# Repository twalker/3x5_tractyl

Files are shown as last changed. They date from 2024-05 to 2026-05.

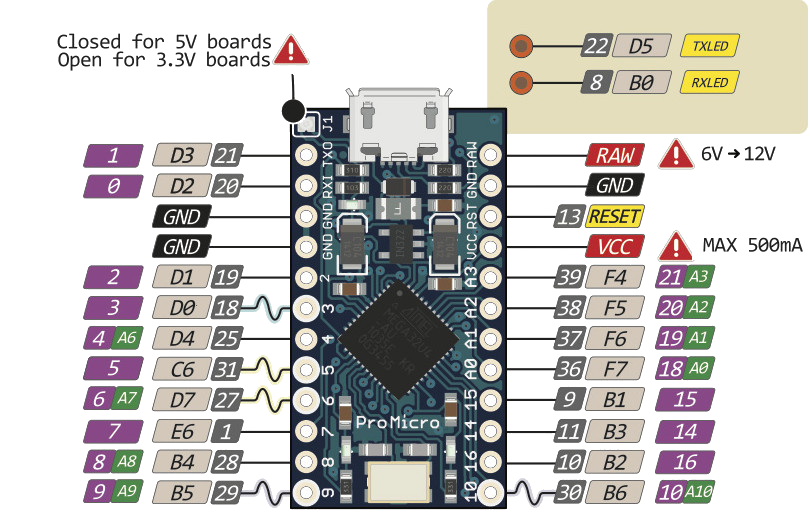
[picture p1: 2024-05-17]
wiring-diagram/pro_micro_pinout2.png

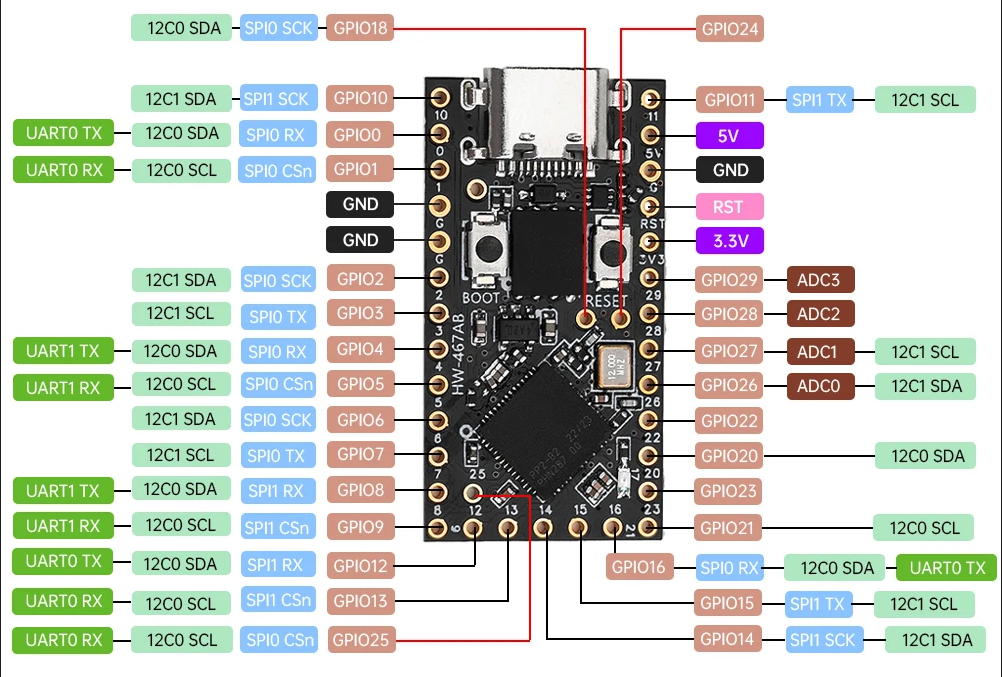
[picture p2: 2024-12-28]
v2/rp2040-promicro-pinout.png

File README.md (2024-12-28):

# 3x5_tractyl

A 3x5 Dactyl keyboard with a trackball on the top left.

# Parts list

- [PMW3389 Motion Sensor](https://www.tindie.com/products/citizenjoe/pmw3389-motion-sensor)
- [Elite-C](https://keeb.io/products/elite-c-low-profile-version-usb-c-pro-micro-replacement-atmega32u4)
- [Cosmos keyboard configurator](https://ryanis.cool/cosmos/beta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)
  v3: https://ryanis.cool/cosmos/beta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
  v4: https://ryanis.cool/cosmos/beta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
  https://ryanis.cool/cosmos/beta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
  Low pro, adjusted stagger, and key spacing:
  https://ryanis.cool/cosmos/beta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
  Lowpro v2:
  https://ryanis.cool/cosmos/beta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
  v2 no web:

https://ryanis.cool/cosmos/beta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

Updated palm wrests:
https://ryanis.cool/cosmos/beta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

Beta v3 WIP:
https://ryanis.cool/cosmos2/beta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

# Dactyl build guides

- https://klotzandrew.com/blog/building-a-dactyl-keyboard-from-scratch
- https://www.reddit.com/r/olkb/comments/c8hjn1/help_me_correctly_programming_my_new_born_dactyl/
- https://github.com/aleung/mini-thumb-dactyl-keyboard
- https://github.com/dereknheiley/compactyl/tree/master
- https://github.com/ArtiomSu/qmk_firmware/tree/artiom_dactyl/keyboards/artiomsu_dactyl
- https://medium.com/swlh/complete-idiot-guide-for-building-a-dactyl-manuform-keyboard-53454845b065
- https://github.com/noahprince22/tractyl-manuform-keyboard

## Issues

- Could not configure dactyl generator with trackball holder. No response to github issue.
- No model for a 38mm trackball. Needed to model a trackball holder in Fusion 360.
- Diode in the wrong direction.
- 3-4 Switch wires disconnected.
- Trackball sensor too far from trackball to register movement.
- Case model had corrupted geometry on thumb cluster bottom.
- Case printing had layer shifts.
- MCU holder was too tight.
- Trackball wiring misconfigured (B2 and B3 in wrong order).
- Dupont connectors pushing and popping keys out--needed to replace microcontroller with 90deg headers.
- Keys popping out -- needed to glue switches down.

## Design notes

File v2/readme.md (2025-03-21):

# V2 - mx

- Ameoba kings with MX switches
- Beta v3

### With trackball

https://ryanis.cool/cosmos/beta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

### Adjusted to MX switches (std key spacing)

https://ryanis.cool/cosmos/beta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

## Adjusted MCU

https://ryanis.cool/cosmos/beta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

## 1.5 u thumbs

https://ryanis.cool/cosmos/beta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

#### Adjusted MCU 2

https://ryanis.cool/cosmos/beta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

### Skree pcb, sensor, and des keycaps

- 15 -> 20 deg column curvature

https://ryanis.cool/cosmos/beta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

Adjusted trackball position
https://ryanis.cool/cosmos/beta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

With left shaper key
https://ryanis.cool/cosmos/beta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

with adjusted MCU
https://ryanis.cool/cosmos/beta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

with larger keys on thumbs (1, 1.25, 1.5)
https://ryanis.cool/cosmos/beta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

With mcu at top (Printed) ( cosmoskreedes_v1):
https://ryanis.cool/cosmos/beta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

Trying another print :
https://ryanis.cool/cosmos/beta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

## Printed left side

Possible issues:

Resolved:

- key spacing is tight with MT3. bearable
- microcontroller mount does not quite fit (blocking screw) -- made 2nd attempt--11.5, 90deg
- Do the single key w/choc sockets fit the ameoba king holders?
- I really want choc spacing --quieter and lighter. Not in this version. Want to reuse wire harness.
- mount PWM3360 seems to have has inadequate clearence (rotated for better access)
- 3mm Ceramic balls seem too small (Need to use glue)

Unresolved:

---

### WIP Choc version:

https://ryanis.cool/cosmos/beta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

with screen and rounded.
https://ryanis.cool/cosmos/beta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

To do:
Try keyspacing: 19.5 x 18.5
Kailh Choc keys are 18mm wide and 17mm tall.
https://ryanis.cool/cosmos/beta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

With mouse thumb key:
https://ryanis.cool/cosmos/beta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

- Adjusted stagger and lowered trackball

```
  pinky: -13
  ring: 0
  middle: 2.8 => 4.5
  index: 0 => -1.5
  inner: 0 => -3.5
```

https://ryanis.cool/cosmos/beta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

Adjusted screen position and rounded sides:
https://ryanis.cool/cosmos/beta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

With right side separated and cleaned up
https://ryanis.cool/cosmos/beta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

Printed prototype 2 ...
Love it.

Tweaks to do:

- Tenting: 15 -> 20 deg?, no. when hangingo the edge there's some tension with 20deg, but otherwise yes.
  x Split the difference: 15 -> 17.5
- Stagger: Good. No changes.
- Ball placement
  x X? + 2-3mm to the right?
  - Y?
  - Z?
- Screen: -Y
  - moved screen to side, so it'd be easy to make a screenless verison. Used 1.5u shaper instead.
- Ring anchor:

  - level instead of sloped-- so the finger doesn't slide off
  - +y 1-3mm
  - maybe rotate 45deg so pinky can rest too

- Thumb anchor key:
  - Maybe -0.5mm - 1mm Z, no.
  - moving ~2mm Y
    Adjustments 1: tenting, move screen, ball placement
    https://ryanis.cool/cosmos/beta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

Adjusted top right anchor:
https://ryanis.cool/cosmos/beta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
With reset holes:
https://ryanis.cool/cosmos/beta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

Repositioned reset holes:
https://ryanis.cool/cosmos/beta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

Repositioned index anchor:
https://ryanis.cool/cosmos/beta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

Power buttion instead of rocker switch:
https://ryanis.cool/cosmos/beta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

Another print

Switch to QMK
https://ryanis.cool/cosmos/beta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

1mm Closer thumbs
https://ryanis.cool/cosmos/beta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

No OLEDs WIP
https://ryanis.cool/cosmos/beta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

https://ryanis.cool/cosmos/beta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

mcu position okay
https://ryanis.cool/cosmos/beta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

No right spacer key
https://ryanis.cool/cosmos/beta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

Updated screws to 7
https://ryanis.cool/cosmos/beta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

trackball mount and 2u left landing spacer, lower left mouse key
https://ryanis.cool/cosmos/beta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

!!another print (fantasy forest green). And built!!

Attempt at wrist wrests:
https://ryanis.cool/cosmos/beta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

---

TODO:
x adjust stagger (especially index)

x lower trackball?
x Adjust angle/location of pinky anchor
x adjust MCU location
x Cleanup right side
x add reset hole

---

# Build

1. Flash MCU, connect sensor, and test trackball (DONE)
2. Glue ceramic balls to crater (DONE)
3. Update Wiring Diagram
4. Use test print to prototype wiring technique with diodes
5. Glue hotswap sockets
6. Wire rows and columns
   - Rows will be composed of diodes with legs (end near center, current outward)
   - Columns use small connector wires
7. Wire TRRS and Reset button
8. Wire Rows and columns
9. Refactor keymap for 38 keys (3x5_4)

### Custom firmware

layout json
https://github.com/qmk/qmk_firmware/blob/master/docs/reference_configurator_support.md
https://github.com/qmk/qmk_firmware/blob/master/docs/reference_info_json.md
https://www.youtube.com/watch?v=bMTp51j7-iY&t=550s

```json
/*
**legend**
layout: A list of key dictionaries comprising the layout. Each key dictionary contains
  x:      The key's X-axis location, in key units from the keyboard's left edge.
  y:      The key's Y-axis location, in key units from the keyboard's top (rear-facing) edge.
  matrix: The matrix position for the key. Example: [0, 4] (row 0, column 4)
*/
    "layouts": {
        "LAYOUT": {
            "layout": [
                // matrix: [RowPosition, ColPosition], "x": ColumnPositon, "y": RowPosition},
                {"matrix": [0, 0], "x": 0, "y": 0},
            ]
        }
    }
```

```json
        "LAYOUT_split_3x5_4": {
            "layout": [
                {"matrix": [0, 0], "x": 0, "y": 0},
                {"matrix": [0, 1], "x": 1, "y": 0},
                {"matrix": [0, 2], "x": 2, "y": 0},
                {"matrix": [0, 3], "x": 3, "y": 0},
                {"matrix": [0, 4], "x": 4, "y": 0},

                {"matrix": [4, 0], "x": 10, "y": 0},
                {"matrix": [4, 1], "x": 11, "y": 0},
                {"matrix": [4, 2], "x": 12, "y": 0},
                {"matrix": [4, 3], "x": 13, "y": 0},
                {"matrix": [4, 4], "x": 14, "y": 0},

                {"matrix": [1, 0], "x": 0, "y": 1},
                {"matrix": [1, 1], "x": 1, "y": 1},
                {"matrix": [1, 2], "x": 2, "y": 1},
                {"matrix": [1, 3], "x": 3, "y": 1},
                {"matrix": [1, 4], "x": 4, "y": 1},

                {"matrix": [5, 0], "x": 10, "y": 1},
                {"matrix": [5, 1], "x": 11, "y": 1},
                {"matrix": [5, 2], "x": 12, "y": 1},
                {"matrix": [5, 3], "x": 13, "y": 1},
                {"matrix": [5, 4], "x": 14, "y": 1},

                {"matrix": [2, 0], "x": 0, "y": 2},
                {"matrix": [2, 1], "x": 1, "y": 2},
                {"matrix": [2, 2], "x": 2, "y": 2},
                {"matrix": [2, 3], "x": 3, "y": 2},
                {"matrix": [2, 4], "x": 4, "y": 2},

                {"matrix": [6, 0], "x": 10, "y": 2},
                {"matrix": [6, 1], "x": 11, "y": 2},
                {"matrix": [6, 2], "x": 12, "y": 2},
                {"matrix": [6, 3], "x": 13, "y": 2},
                {"matrix": [6, 4], "x": 14, "y": 2},

                {"matrix": [3, 1], "x": 1, "y": 3},
                {"matrix": [3, 2], "x": 2, "y": 3},
                {"matrix": [3, 3], "x": 3, "y": 3},
                {"matrix": [3, 4], "x": 4, "y": 3},

                {"matrix": [7, 0], "x": 10, "y": 3},
                {"matrix": [7, 1], "x": 11, "y": 3},
                {"matrix": [7, 2], "x": 12, "y": 3},
                {"matrix": [7, 3], "x": 13, "y": 3}
            ]
        }
```

homerow mod implementation to try:
https://www.reddit.com/r/ErgoMechKeyboards/comments/1f18d8h/i_have_fixed_home_row_mods_in_qmk_for_everyone/

```
#undef QUICK_TAP_TERM
#undef TAPPING_TERM
#define TAPPING_TERM 250
#define QUICK_TAP_TERM 120
#define PERMISSIVE_HOLD
#define IGNORE_MOD_TAP_INTERRUPT
```

matrix explanation (see keymap setup: 1830 ):
https://www.youtube.com/watch?v=bMTp51j7-iY&t=551s

---

## Case adjustments needed

- [x] 1mm or more bottom clearance for mouse sensor PCB, or raise ball up--it was touching bottom plate.
- [x] Raise trackball could up (z) a few millimeters.
- [x] Remove the reset button hole
- [x] Upper corner of sensor PCB touched wall and needed to be rounded.
- [x] Use the Skree trackball mount instead of the QMK on (!! Skree trackball PCB footprint only works for wireless.)
- [ ] Reorder row pins for a clear left to right wiring
      From:

```
        "rows": [ "GP16", "GP15", "GP14", "GP13" ]
```

To:

```
        "rows": [ "GP12", "GP13", "GP14", "GP15" ]
```

https://ryanis.cool/cosmos/beta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

https://ryanis.cool/cosmos/beta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

Trackball Repositioned
https://ryanis.cool/cosmos/beta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

a bit more
https://ryanis.cool/cosmos/beta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

mcu's Repositioned
https://ryanis.cool/cosmos/beta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

lower tenting angle 17.5 -> 15, lower thumb clusters and add row curve
https://ryanis.cool/cosmos/beta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

Reposition trackball toward index finger
https://ryanis.cool/cosmos/beta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

Printed 2.4!!!
Mouse sensor mount is wrong one! Need the QMK mount, not the Skree mount.
TODO: Reuse left case for wireless version.

verison 2.41
https://ryanis.cool/cosmos/beta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

### Printed 2.4.1!!!!

Adjustments
Case Tweaks

### TODO:

- [ ] R2C5 hotswap bumps into thumb cluster, needs more room. highten super thumb or move away from matrix.
- [ ] trackball mount screws obscured by case screws

---

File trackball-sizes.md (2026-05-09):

## Trackball sizes

- 34mm Standard (too small)
- 38mm Ploopy Nano (just right)
- 45mm Ploopy Adept (tracking issues?)

## Cosmos keyboard supported sizes
- 25mm
- 34mm (std)
- nano size not availble
- 40mm (Kensington Orbit)
- 43mm (Logitech Trackman T-RB22)
- 44mm (Kensington and Elecom DEFT)
- 45mm (Ploopy classic, adept)
- 46mm (Microsoft Trackball Explorer)
- 50mm
- 52.5mm (Standard size of snooker balls)
- 57.15mm (Standard size of American billiard balls)

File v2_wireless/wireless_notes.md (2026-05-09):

## Wireless version

starting with version 2.41

- [x] Thumb supers heightened
- [x] oled screens added (do not persist in cosmos)
- [ ] battery space determined

https://ryanis.cool/cosmos/beta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

with switch holes
https://ryanis.cool/cosmos/beta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

3 screws and mcu's placed
https://ryanis.cool/cosmos/beta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

switches added 5x7
https://ryanis.cool/cosmos/beta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

cosmos_choc_hotswap_wireless_v2.5
https://ryanis.cool/cosmos/beta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
was somehow deleted !!!!

Printed:
- Galaxy Black

cosmos_choc_hotswap_wireless_v2.6 -- redone; Cosmos is forgetting oled screens!!!

https://ryanis.cool/cosmos/beta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
---
## clemenza plus
https://ryanis.cool/cosmos/beta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

https://ryanis.cool/cosmos/beta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

https://ryanis.cool/cosmos/beta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

only on oled:
https://ryanis.cool/cosmos/beta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

With 7.5mm  BTU
https://ryanis.cool/cosmos/beta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

closer thumb cluster
https://ryanis.cool/cosmos/beta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

balls for trackball
https://ryanis.cool/cosmos/beta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

with hillside pcbs
https://ryanis.cool/cosmos/beta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

Luca printed with 5 Column, hillside PCBs, and BUILt.

TODO for Luca v2:
Make 2 versions, a 45mm and a 34mm for work.

-[x] use 3DP sockets instead of pcb
-[x] Fewer base screws
-[x] Don't block sensor screw holes
-[x] Sit's too high at twenty degree angle. Can the overall case be lowered? Smaller ball, or move ball right. smaller ball
-[x] Adust Left power switch and MCU position if possible. 
-[x] Ball position may be a bit too far left, wait so see. No, it's great for 45mm
-[x] Try 7.5 BTU for trackball
-[x] Smaller ball

https://ryanis.cool/cosmos/beta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

34mm smaller ball
https://ryanis.cool/cosmos/beta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
 
 smaller power switch
 https://ryanis.cool/cosmos/beta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

fewer screws
https://ryanis.cool/cosmos/beta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

Move ball offset x from 0 to 11 like pentangeli 
https://ryanis.cool/cosmos/beta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

Lower thumb cluster offset Z from 7.1 to 9
https://ryanis.cool/cosmos/beta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

Back to 45mm ball
https://ryanis.cool/cosmos/beta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

Printing

TODO:
- Fix thumb key spacing
- Rewire columns to be more vertically aligned.
- Add dongle for better mouse responsiveness?

---
34mm ball, adusted thumb key spacing, hillside PCBs
name: luca_v2_hs_sm
https://ryanis.cool/cosmos/beta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

Printed
TODO:
- [x] Fix thumb key rotation to match pentangeli
- [ ] move ball right--further towad to index
- [ ] Rethink power switch
- [ ] consider reset button hole

Fixed thumb key

https://ryanis.cool/cosmos/beta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
---
Moved ball, 12 => 8 sides.

https://ryanis.cool/cosmos/beta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

Add reset switch hole:
https://ryanis.cool/cosmos/beta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
https://ryanis.cool/cosmos/beta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
Adjust reset hole to 4.5mm
https://ryanis.cool/cosmos/beta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

Printed with wrong 3dp sockets

fixed sockets
https://ryanis.cool/cosmos/beta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

Assembled (2/22/2026)

### hs sm TODO:
- [x] move trackball back left
- [x] remove reset switch hole
- [x] add extra screws
- [x] adjust power switch width
Use this case for next hillside pcb small trackball case:
https://ryanis.cool/cosmos/beta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

### Back to 45mm with rollers (supposedly quieter)
## hs lg WIP (with rollers)
https://ryanis.cool/cosmos/beta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
https://ryanis.cool/cosmos/beta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

bumpon bottom
https://ryanis.cool/cosmos/beta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

To print: luca v2 hs_lg:
https://ryanis.cool/cosmos/beta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

luca_v2_hs_lg.3mf

v2.1 (larger power switch holes)
https://ryanis.cool/cosmos/beta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

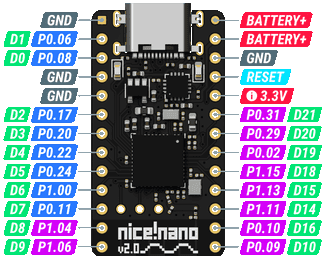
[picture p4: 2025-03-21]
wiring-diagram/nice_nano_pinout-v2_cropped.png

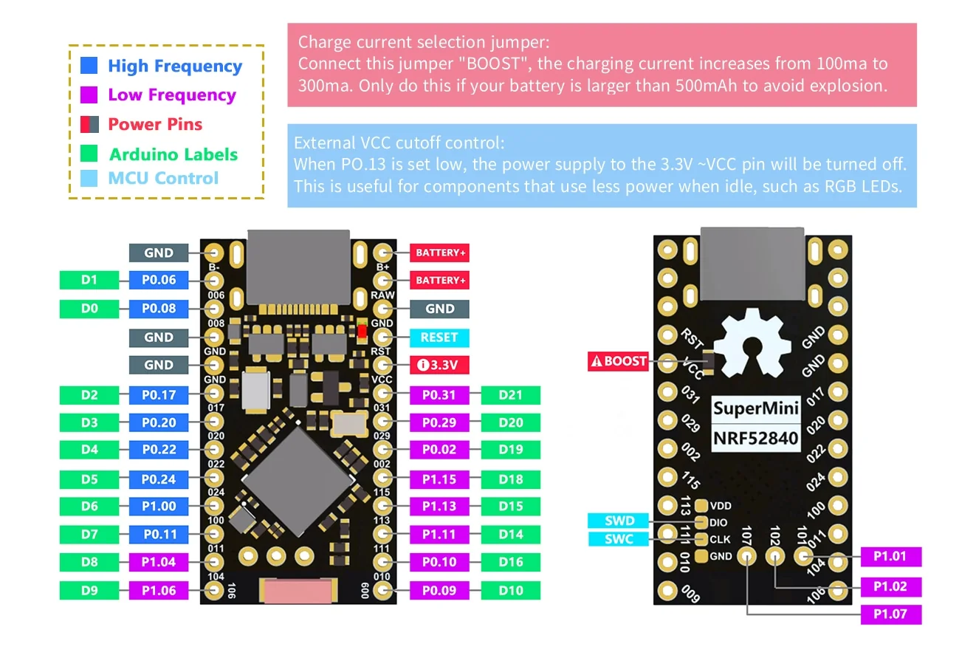
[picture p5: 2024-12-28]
wiring-diagram/supermini-nrf52840-a-6-nice-nano-2-0-compatible-mcu-pinout.webp

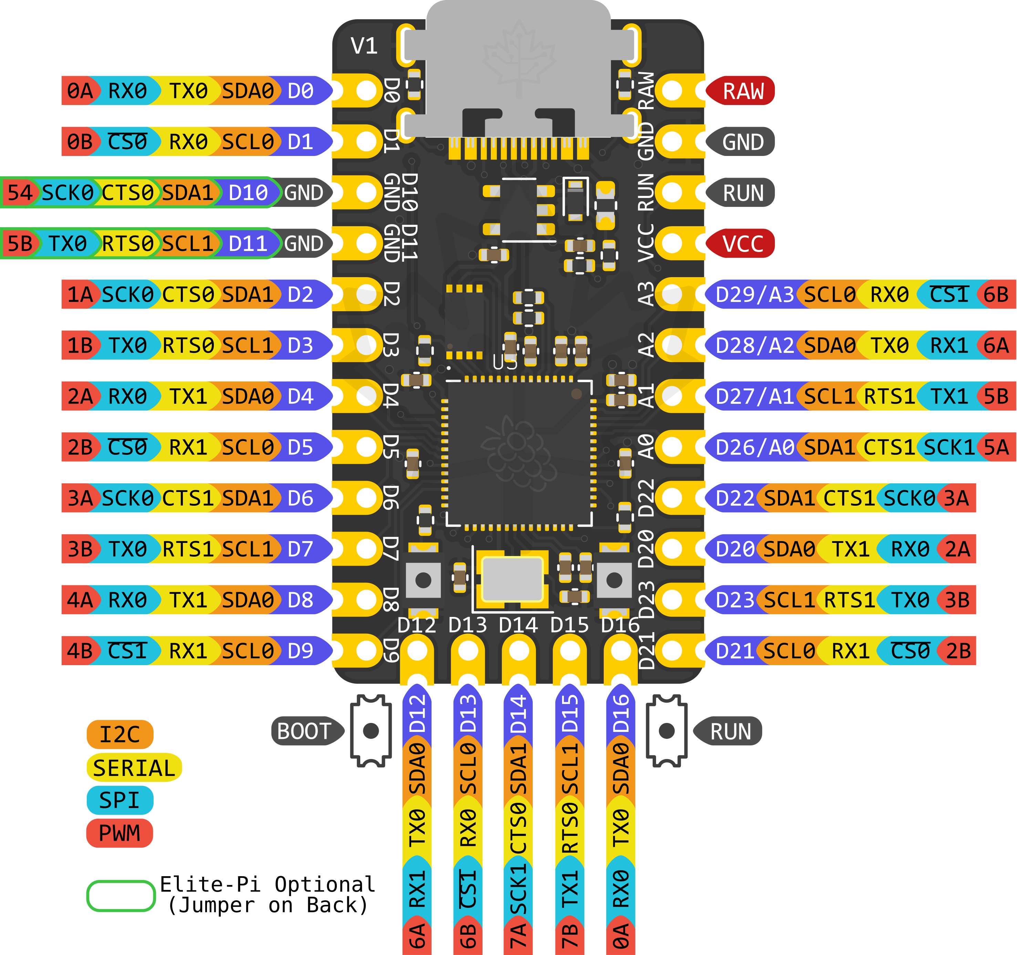
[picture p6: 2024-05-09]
wiring-diagram/Elite-Pi_Pinout-Bottom.png

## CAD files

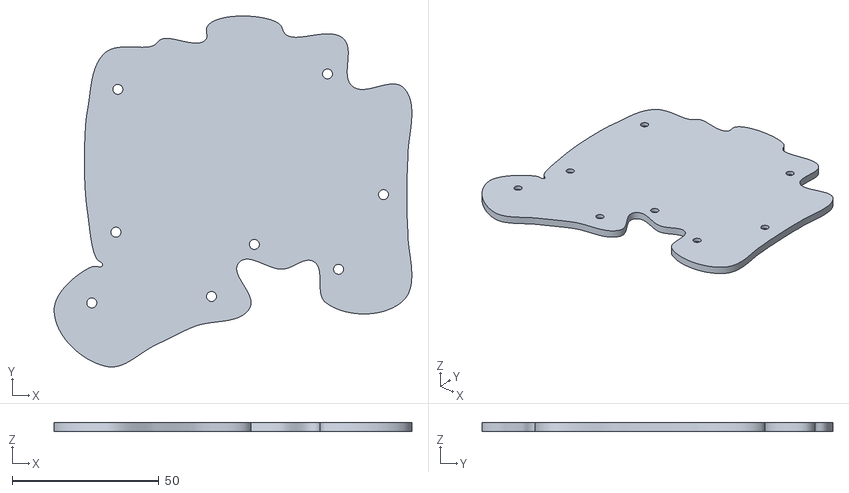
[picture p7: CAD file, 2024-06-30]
case/lowprocosmotyl2-plate-right.stl
122.0 x 119.7 x 3.00

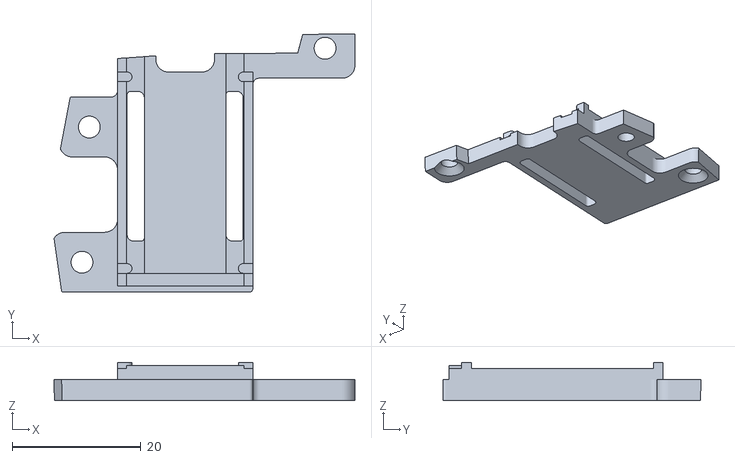
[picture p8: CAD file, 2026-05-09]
clemenza-plus/clemenza-plus_v1-holderright.stl
46.8 x 40.1 x 5.97

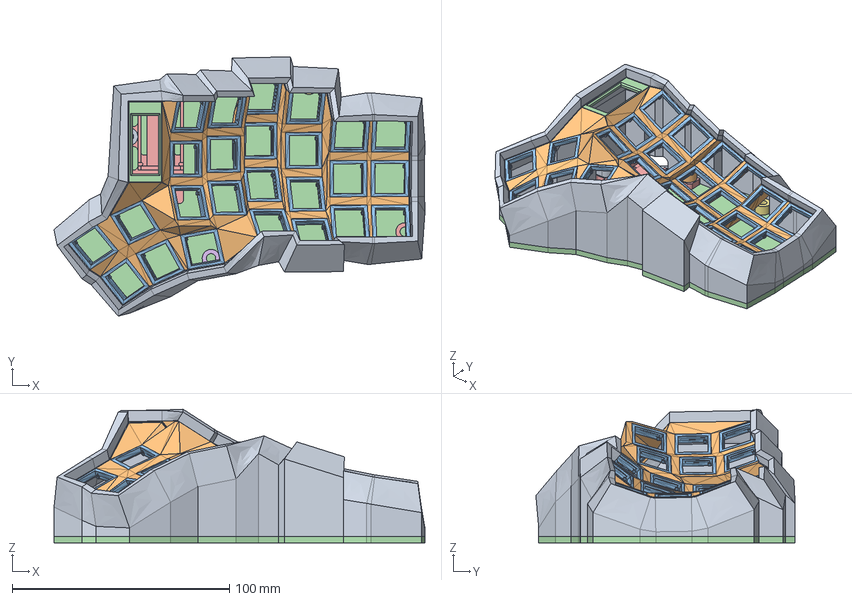
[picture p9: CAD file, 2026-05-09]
luca/luca_v1.0right.step
170.9 x 119.5 x 61.5 mm

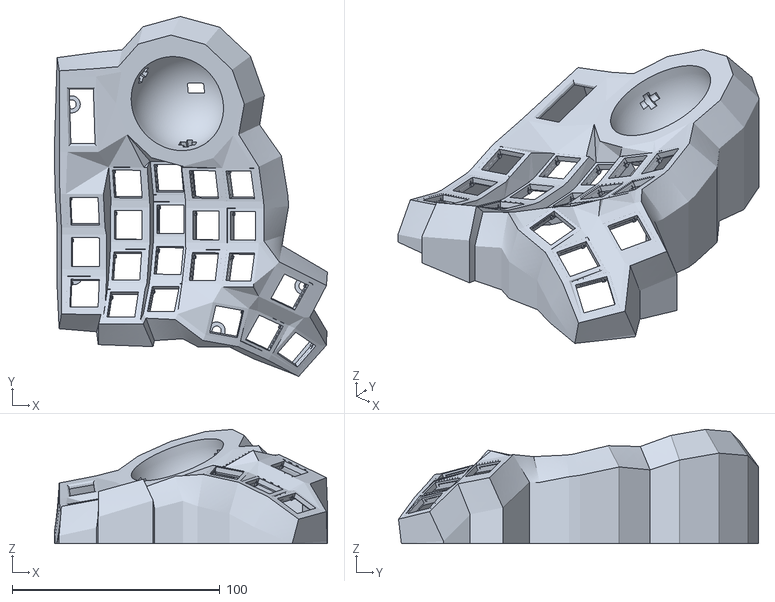
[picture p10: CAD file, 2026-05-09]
luca/luca_v2_hs_lg/luca_v2_hs_lg-caseleft.stl
131.3 x 173.2 x 54.9

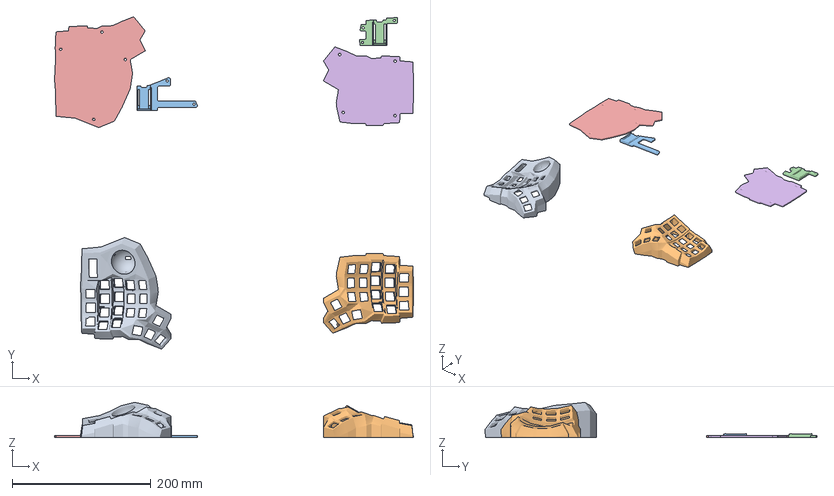
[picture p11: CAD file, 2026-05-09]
luca/luca_v2_hs_sm/luca_v2_hs_sm.3mf
518.0 x 479.6 x 50.9 mm
luca_v2_hs_sm-caseleft.stl
luca_v2_hs_sm-caseright.stl
luca_v2_hs_sm-holderleft.stl
luca_v2_hs_sm-holderright.stl
luca_v2_hs_sm-plateleft.stl
luca_v2_hs_sm-plateright.stl

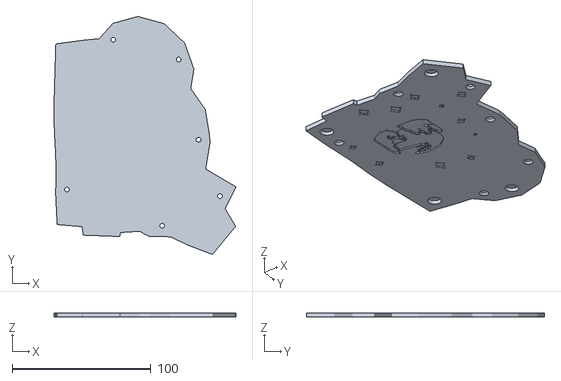
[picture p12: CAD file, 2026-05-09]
luca_v2.1_hs/luca_v2.1_hs_lg-plateleft.stl
131.3 x 171.8 x 3.00

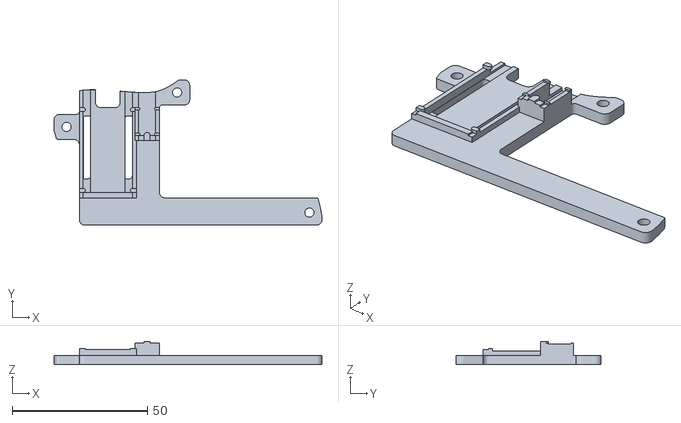
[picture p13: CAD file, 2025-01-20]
v2/cosmos_choc_hotwap_v2.41/cosmos_choc_hotwap_v2.41-holderleft.stl
98.9 x 53.6 x 8.50

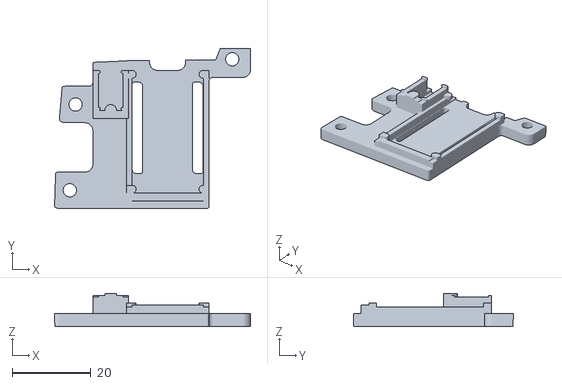
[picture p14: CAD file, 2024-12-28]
v2/cosmoskreedes_v1-holderright.stl
49.9 x 40.8 x 8.50

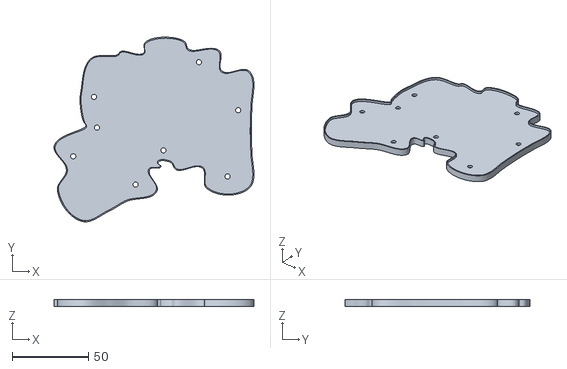
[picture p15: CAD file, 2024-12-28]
v2/costmos_choc_hotswap_v2/cosmos_choc_hotwap_v2.2-plateright.stl
131.1 x 121.1 x 4.50

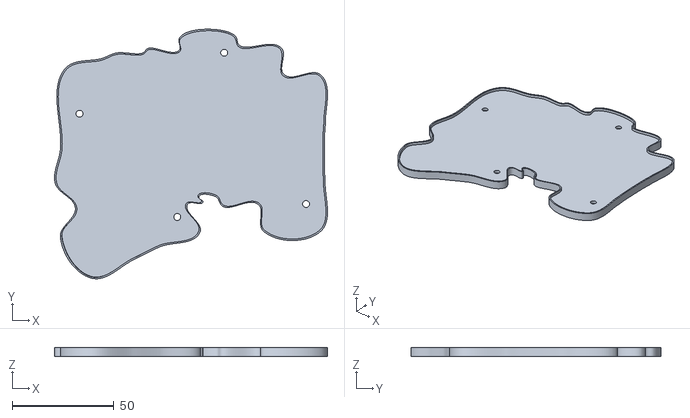
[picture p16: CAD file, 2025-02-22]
v2_wireless/cosmos_choc_hotwap_wireless_v2.5-plateright.stl
134.1 x 122.6 x 4.50

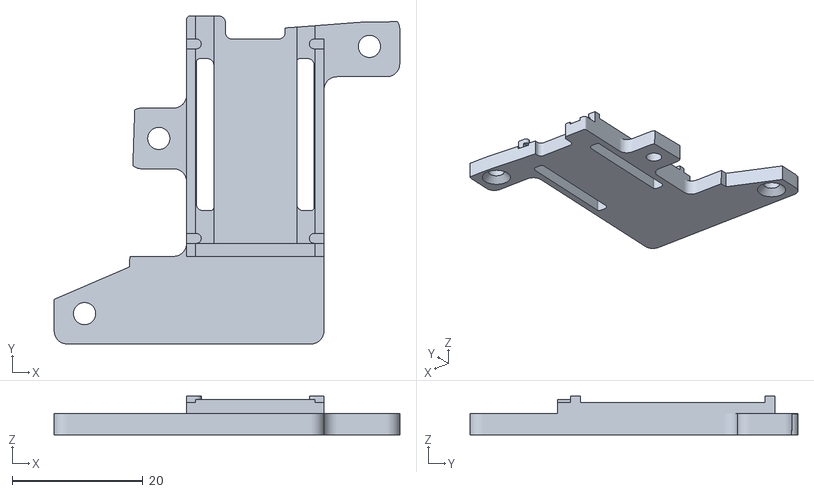
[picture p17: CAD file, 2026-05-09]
wireless_thumb_v1/v1.4/clemenza-thumb_v1.4-holderright.stl
52.9 x 50.2 x 5.97

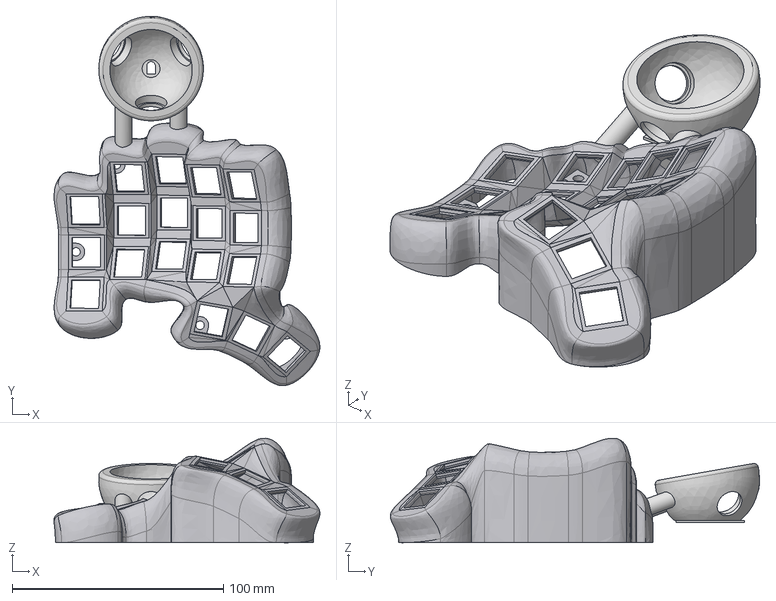
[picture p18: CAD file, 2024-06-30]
case/lowprocosmotyl2-noweb3-left-shaprexport.step
126.0 x 174.9 x 49.5 mm
38mmTrackBallHolder v18.step
Imported 00

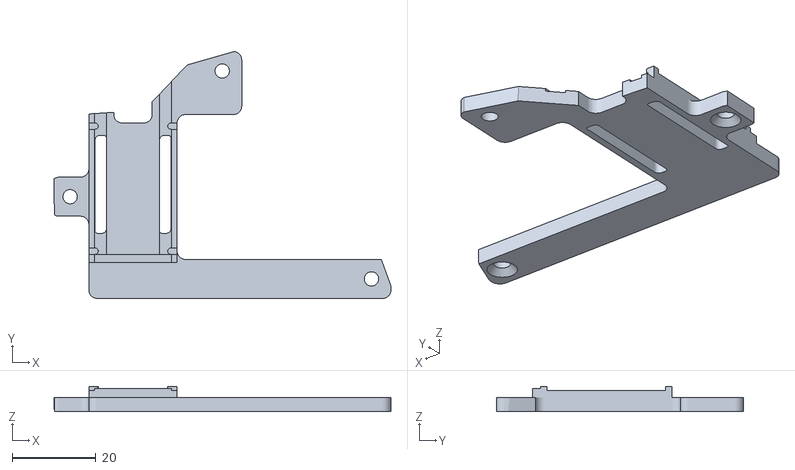
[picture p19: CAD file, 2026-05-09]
clemenza-plus/clemenza-plus_v1-holderleft.stl
80.3 x 58.8 x 5.97

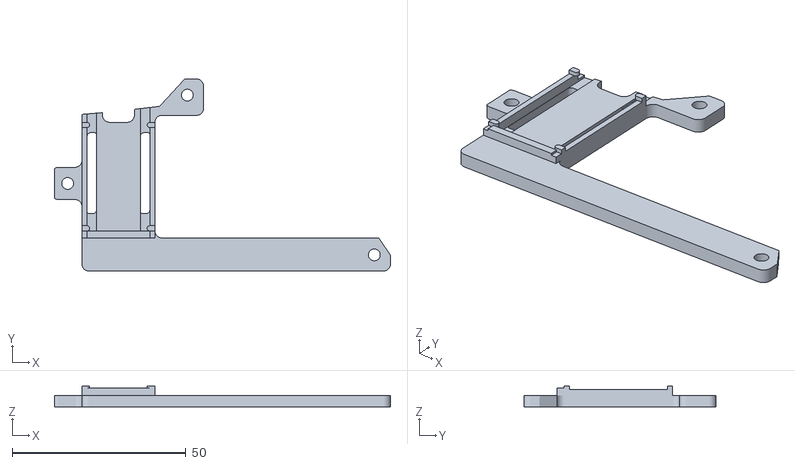
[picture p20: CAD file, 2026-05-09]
luca/luca_v2_hs_lg/luca_v2_hs_lg-holderleft.stl
96.7 x 55.3 x 5.97

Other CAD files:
luca/luca_v2_hs_sm/luca_v2_hs_sm-plateright.stl
luca_v2.1_hs/luca_v2.1_hs_lg-holderright.stl
v2/cosmos_choc_hotwap_v2.41/cosmos_choc_hotwap_v2.41-plateright.stl
v2/cosmotylmt3v1-plateleft.stl
case/38mmTrackBallHolder.3mf
case/Mount Plate Test.step
case/Mount Plate Test.stl
case/PMW3360 v12 v1.step
case/PMW3360 v12 v1.stl
case/_archived/3x5_WHOLE_MINIDOX_LEFT_PLATE.dxf
case/_archived/3x5_WHOLE_MINIDOX_LEFT_PLATE.step
case/_archived/3x5_WHOLE_MINIDOX_LEFT_PLATE_cadquery.stl
case/_archived/3x5_WHOLE_MINIDOX_LEFT_TOP_cadquery.stl
case/_archived/3x5_WHOLE_MINIDOX_RIGHT_PLATE.dxf
case/_archived/3x5_WHOLE_MINIDOX_RIGHT_PLATE.step
case/_archived/3x5_WHOLE_MINIDOX_RIGHT_PLATE_cadquery.stl
case/_archived/3x5_WHOLE_MINIDOX_RIGHT_TOP_cadquery.stl
case/_archived/cosmotyl2-case-left.stl
case/_archived/cosmotyl2-case-right.stl
case/_archived/cosmotyl2-holder-left.stl
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

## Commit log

2024-05-09 Add a mess of files
    [3x5_WHOLE_MINIDOX_LEFT_PLATE.dxf, 3x5_WHOLE_MINIDOX_LEFT_PLATE.step, 3x5_WHOLE_MINIDOX_LEFT_PLATE_cadquery.stl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]
2024-05-12 cleanup mess. partially
    [3x5_WHOLE_MINIDOX_LEFT_PLATE.dxf, 3x5_WHOLE_MINIDOX_LEFT_PLATE.step, 3x5_WHOLE_MINIDOX_LEFT_PLATE_cadquery.stl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]
2024-05-17 Update to elite-c
    [cosmotyl4-left.3mf, cosmotyl4-right.3mf, cosmotyl4-wristrests.3mf]
2024-06-30 Fix trackball pinout B2/B3 swap
    [38mmTrackBallHolder.3mf, Mount Plate Test.step, Mount Plate Test.stl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]
2024-12-28 Add more v2 notes
    [cosmos_choc_hotwap_v1.3mf, cosmos_choc_hotwap_v2.2-holderleft.stl, cosmos_choc_hotwap_v2.2-holderright.stl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]
2025-01-20 Add cases for 2.4
    [cosmos_choc_hotwap_v2.3-holderleft.stl, cosmos_choc_hotwap_v2.3-holderright.stl, cosmos_choc_hotwap_v2.3-plateleft.stl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]
2025-02-22 add case for wireless variant
    [cosmos_choc_hotwap_wireless_v2.5-holderleft.stl, cosmos_choc_hotwap_wireless_v2.5-holderright.stl, cosmos_choc_hotwap_wireless_v2.5-plateleft.stl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]
2025-02-23 start printing wireless verion
2025-04-28 start on wireless_thumb
    [pentangeli-thumb_v1-caseleft.stl, pentangeli-thumb_v1-caseright.stl, pentangeli-thumb_v1-holderleft.stl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]
2025-06-07 Add clemenza files
    [clemenza-thumb_v1.3-caseleft.stl, clemenza-thumb_v1.3-caseright.stl, clemenza-thumb_v1.3-holderleft.stl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]
2026-05-09 luca and trackball sizes
    [clemenza-plus_v1-caseleft.stl, clemenza-plus_v1-caseright.stl, clemenza-plus_v1-holderleft.stl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]
